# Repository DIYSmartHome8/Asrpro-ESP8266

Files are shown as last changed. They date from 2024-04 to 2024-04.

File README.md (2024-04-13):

# Asrpro-ESP8266<br>
天问离线语音模块ASRPro接入Homeassistant<br>
一直想找个离线的语音方案，最近朋友们推荐ASRPRO，说里面能跑神经网络，牛逼的很。<br>
体验了吧，确实太方便了。然后就有了这个分享。<br>
全开源：包含Gerber，3D Step，天问源码，ESPhome源码，稍后整理依次更新。。。<br>
# 1、简介<br>
板子包含ASRPro，ESP8266，一个温湿度传感器（但实测发现，温度显示不正常，建议大家空贴。）一个红外接收，两个红外发送，用的IO跟红外伴侣一样。我这个例程，其实就是拿红外伴侣来改的。<br>
# 2、框图<br>
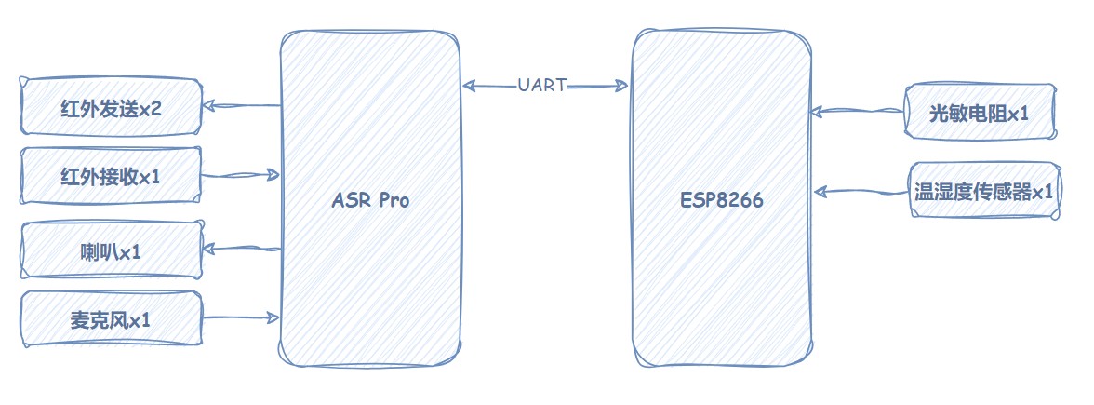
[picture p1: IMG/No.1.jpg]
<br>
温湿度传感器可能由于LDO或模块发热，数据不对，又或者是要校准什么的，没找到原因，所以不建议贴。<br>
# 3、3D图<br>
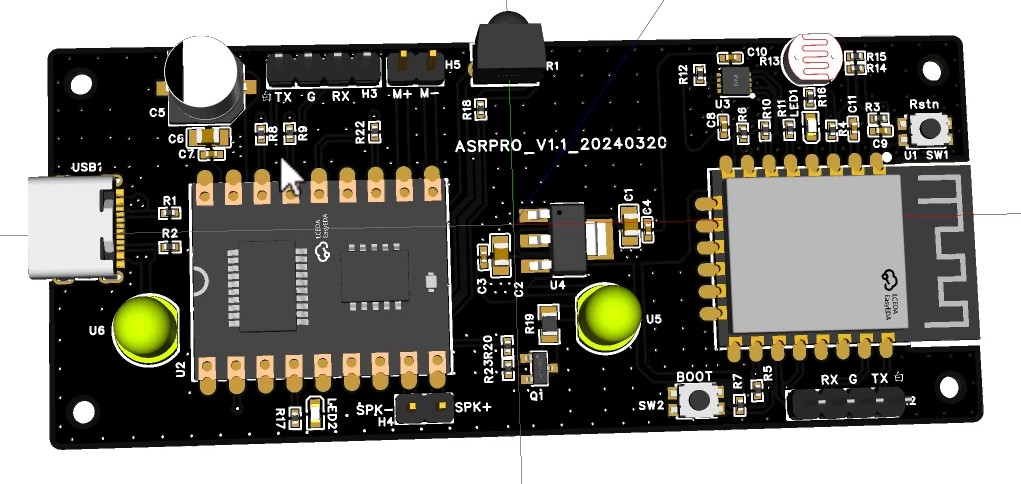
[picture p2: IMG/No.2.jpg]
<br>
# 4、成品长这样<br>
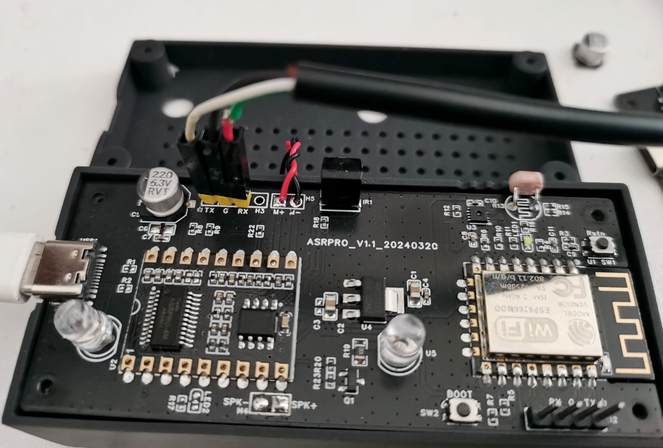
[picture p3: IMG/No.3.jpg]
<br>
碰巧是全黑的，所以我叫它小黑同学<br>
这个喇叭的线，这样焊接的，盖子开多了，有摇断的风险<br>
喇叭是直接卡进去的，买了两种喇叭，有一种尺寸不对<br>
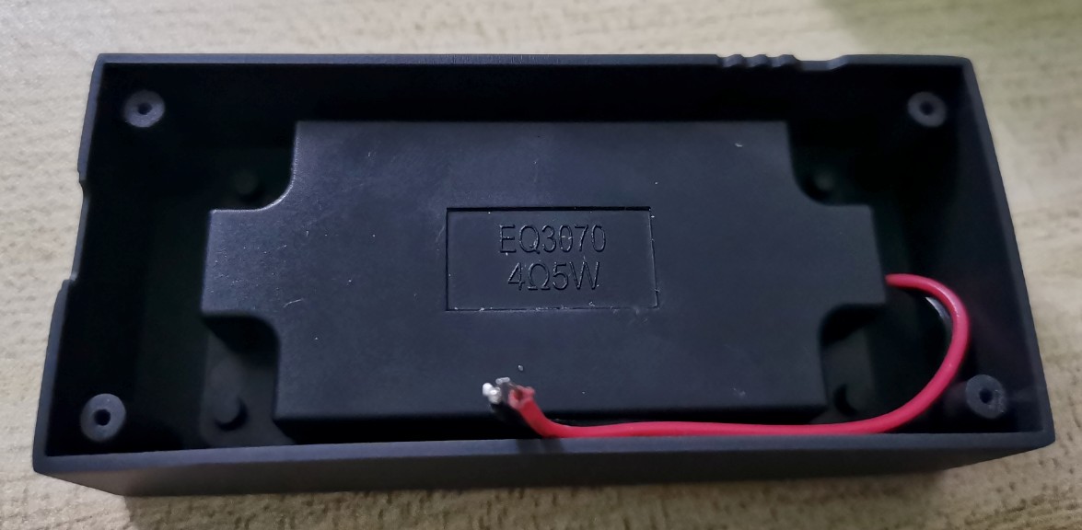
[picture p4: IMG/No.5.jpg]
<br>
喇叭定位及孔大小是按这个尺寸设计的<br>
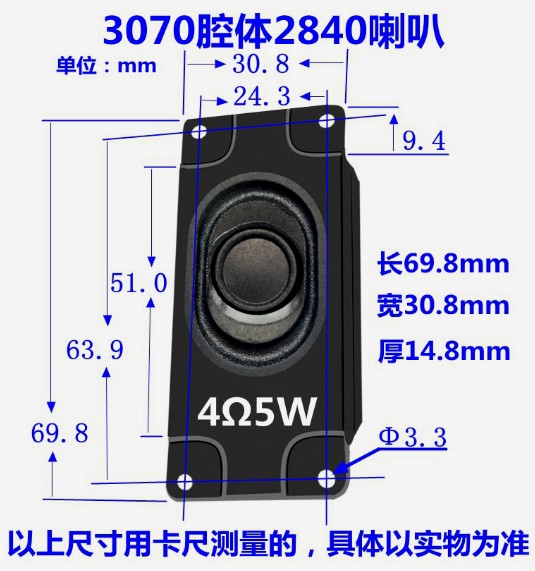
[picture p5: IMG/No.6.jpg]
<br>
# 5、天问Block<br>
非常简单，通过串口把识别到的命令发给ESP8266，8266再通过WIFI传给Homeassistant<br>
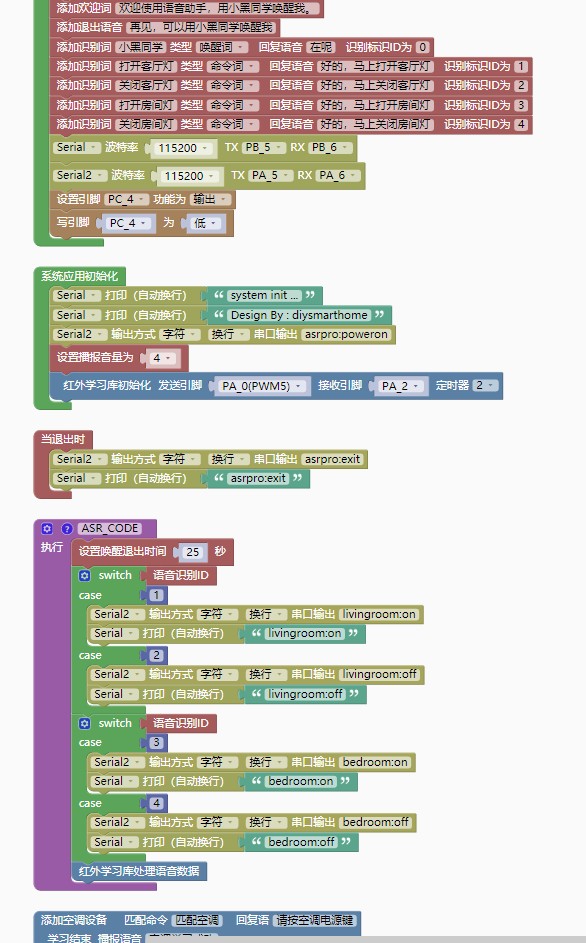
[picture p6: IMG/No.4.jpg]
<br>
# 6、ESP8266部分<br>
ESP8266用Esphome处理，也非常简单，yaml及串口源码均已开源。
# 7、最终效果视频<br>
顺带介绍了没用官方下载电路时的烧录时机<br>
https://www.bilibili.com/video/BV1GF4m1N7by

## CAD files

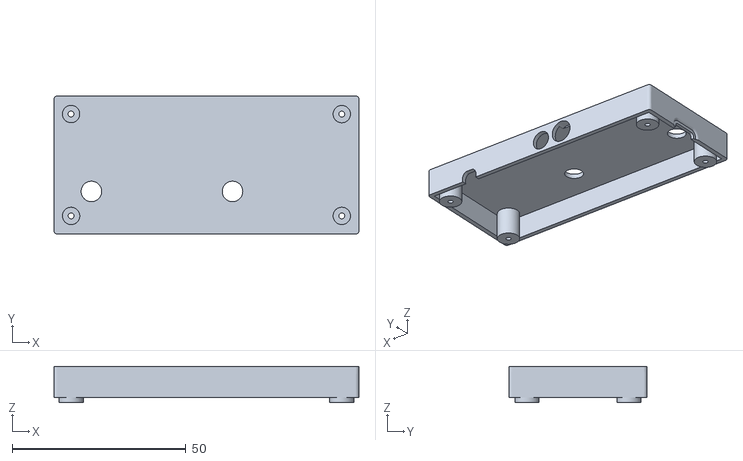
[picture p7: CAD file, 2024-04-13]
3D外壳/ASRPRO_ESP8266_TOP.stl
87.8 x 39.8 x 10.5

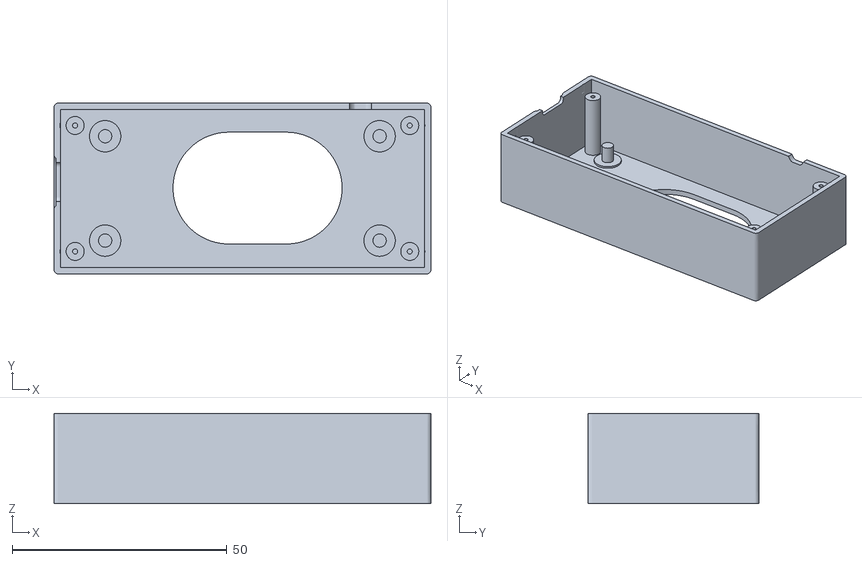
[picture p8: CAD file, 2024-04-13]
3D外壳/ASRPRO_ESP8266_BOT.stl
87.8 x 39.8 x 21.0

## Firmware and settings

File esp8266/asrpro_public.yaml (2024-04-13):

substitutions:
  devicename: asrpro
  friendly_name: $devicename
  hw_version: v1.0

esphome:
  name: ${devicename}
  friendly_name: ${friendly_name}
  platform: ESP8266
  board: d1_mini
  esp8266_restore_from_flash: False
  includes:
    - components/asrpro_uart_command.h

wifi:
  networks:
    - ssid: !secret ssid1
      password: !secret ssid1_password
  ap:
    ssid: ${devicename}
    password: diysmarthome
    ap_timeout: 2min
  fast_connect: False
  power_save_mode: none
  domain: .local

captive_portal:

ota:
  password: !secret ota_password

api:
  encryption:
    key: !secret api_key
  reboot_timeout: 0s

web_server:
  port: 80
  auth:
    username: admin
    password: !secret web_password

# Enable logging
logger:
  esp8266_store_log_strings_in_flash: false
  level: ERROR
  # baud_rate: 0
  baud_rate: 115200
  hardware_uart: UART1

uart:
  id: asrpro_uart
  tx_pin: GPIO15
  rx_pin: GPIO13
  baud_rate: 115200
  parity: NONE
  stop_bits: 1

i2c:
  sda: GPIO12
  scl: GPIO14
  scan: True
  id: bus_a

sensor:
  - platform: adc
    pin: A0
    name: Brightness
    update_interval: 50s
    device_class: illuminance
    unit_of_measurement: lx
    filters:
      - lambda: |-
          return round((x / 10000.0) * -2000000.0 + 200);
  - platform: sht3xd
    heater_enabled: false
    address: 0x44
    i2c_id: bus_a
    temperature:
      name: Temperature
      id: "temperature"
    humidity:
      name: Humidity
      id: "humidity"
    update_interval: 10s
  - platform: wifi_signal
    name: ESP RSSI
    update_interval: 60s
  - platform: template
    name: ESP Free Memory Byte
    id: id_esp_free_memory_byte
    lambda: |-
      return ESP.getFreeHeap();
    filters:
      - multiply: 0.001
    unit_of_measurement: "KB"
    update_interval: 30s
  - platform: uptime
    name: ESP Uptime Sensor
    id: uptime_sensor
    update_interval: 3600s
    internal: true
    on_raw_value:
      then:
        - text_sensor.template.publish:
            id: uptime_human
            state: !lambda |-
              int seconds = round(id(uptime_sensor).raw_state);
              int days = seconds / (24 * 3600);
              seconds = seconds % (24 * 3600);
              int hours = seconds / 3600;
              seconds = seconds % 3600;
              int minutes = seconds /  60;
              seconds = seconds % 60;
              return (
                (days ? String(days) + "d " : "") +
                (hours ? String(hours) + "h " : "") +
                (minutes ? String(minutes) + "m " : "") +
                (String(seconds) + "s")
              ).c_str();

button:
  - platform: restart
    name: ESP Restart
    entity_category: config
  - platform: factory_reset
    disabled_by_default: True
    name: ESP Factory Reset
    id: factory_reset_all

text_sensor:
  - platform: template
    name: ESP Uptime
    id: uptime_human
    icon: mdi:clock-start
  - platform: wifi_info
    ip_address:
      name: ESP IP Address
    mac_address:
      name: ESP MAC
  - platform: custom
    lambda: |-
      auto my_custom_sensor = new UartReadLineSensor(id(asrpro_uart));
      App.register_component(my_custom_sensor);
      return {my_custom_sensor};
    text_sensors:
      name: ASRPRO CMD
      id: "uart_readline"

light:
  - platform: status_led
    name: Status Led
    id: light_status_led
    output: status_led_gpio
    internal: true

output:
  - platform: esp8266_pwm
    id: status_led_gpio
    pin: GPIO16
    inverted: true

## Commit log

2024-04-13 创建工程
    [ASRPRO_ESP8266_BOT.stl, ASRPRO_ESP8266_TOP.stl]
2024-04-13 添加Gerber
